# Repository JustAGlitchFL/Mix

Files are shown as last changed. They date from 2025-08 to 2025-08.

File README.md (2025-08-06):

# Mix
A multipurpose audio-focused console

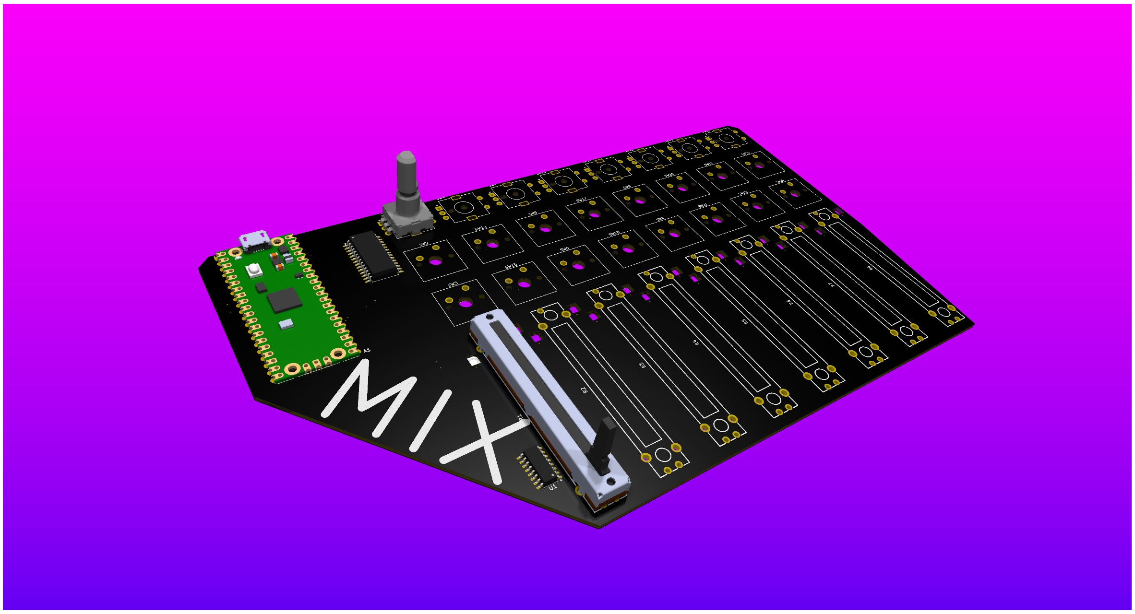
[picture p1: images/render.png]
render

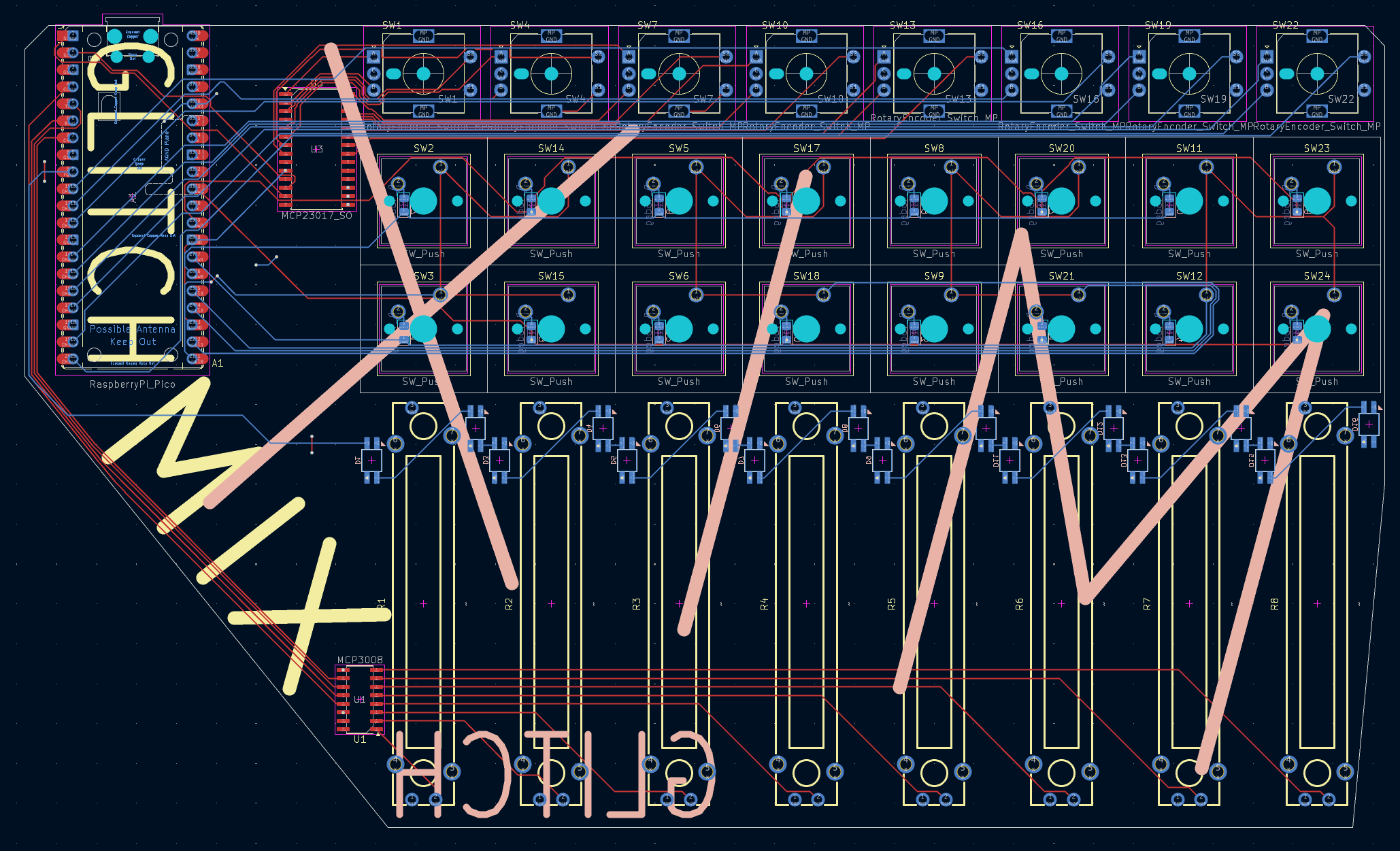
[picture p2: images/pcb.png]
pcb

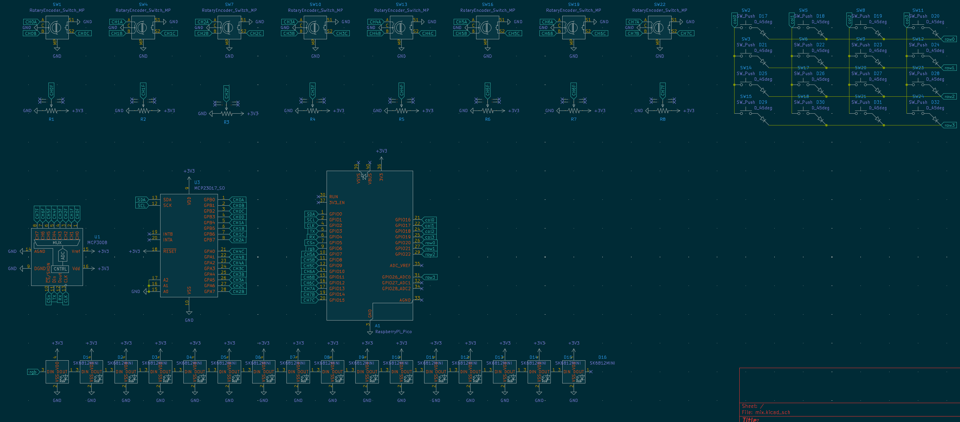
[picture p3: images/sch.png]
sch

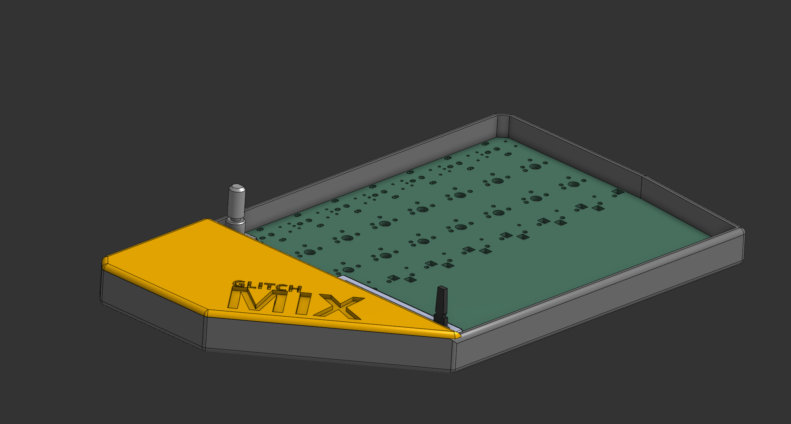
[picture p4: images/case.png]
case


## Why
I find myself constantly tuning my audio mix from different apps through windows, and would like a panel to adjust levels on the fly. I also wanted to use this for mixing audio for music and video projects, so I included 8 channels. Each channel has a slider for feed volume, an encoder for monitoring volume, a solo button, and a mute button. Everything is remappable to select functions for your usecase. I also included 2 neopixels per channel, one for status, and one for leveling by color.

## Assembly
Like [Timeline](https://github.com/justaglitchfl/timeline), ~~no case for this one~~ CASE FILES AVAILABLE NOW, as I want that raw PCB aesthetic. Solder everything together, good luck with the SMD for the ADC and IO expander! Might do a case when I get to uni and have access to actually functional printers if I get tired of the pcb as is. As with my other projects recently, drop some 3M 2229 on the back to protect it/the table, and to keep it in place (I love this stuff).

## BOM
|q  |part |link |price |total  |
|---|---|---|---|---|
|1  |pcb | |$42.60 |$128.78|
|16 |switches |https://www.amazon.com/Kailh-Box-Switches-Mechanical-Keyboards/dp/B09WYVJ4F9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|$25.98 | |
|8  |ECE11 |https://lcsc.com/product-detail/Rotary-Encoders_ALPSALPINE-EC11E18244AU_C202365.html |$15.71 | |
|8  |slide potentiometer |https://lcsc.com/product-detail/Potentiometers-Variable-Resistors_BOURNS-PTA4543-2015DPB103_C17444183.html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 |$14.16 | |
|1  |MCP23017_SO |https://lcsc.com/product-detail/I-O-Expanders_MICROCHIP-MCP23017T-E-SO_C629440.html?s_z=n_MCP23017_SO |$1.94 | |
|1  |MCP3008 |https://lcsc.com/product-detail/Analog-to-Digital-Converters-ADC_MICROCHIP-MCP3008T-I-SL_C2651321.html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 |$3.30 | |
|16 |0805 signal diode | |have on hand| |
|16 |sk6812 mini e | |have on hand| |
|1  |pi pico usbc (i wan orph pico)|https://www.aliexpress.us/item/3256807183354679.html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 |$3.56 | |
|1  |lcsc s+h | |$21.53 | |

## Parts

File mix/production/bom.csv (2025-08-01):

Designator | Footprint | Quantity | Value | LCSC Part #
A1 | RaspberryPi_Pico_Common_Unspecified | 1 | RaspberryPi_Pico
D1, D10, D11, D12, D13, D14, D15, D16, D2, D3, D4, D5, D6, D7, D8, D9 | SK6812MINI-E | 16 | SK6812MINI
D17, D18, D19, D20, D21, D22, D23, D24, D25, D26, D27, D28, D29, D30, D31, D32 | 0805 | 16 | D_45deg
R1, R2, R3, R4, R5, R6, R7, R8 | RES-ADJ_PTA4543-2015CPB102 | 8 | ~
SW1, SW10, SW13, SW16, SW19, SW22, SW4, SW7 | RotaryEncoder_Alps_EC11E-Switch_Vertical_H20mm_MountingHoles | 8 | RotaryEncoder_Switch_MP
SW11, SW12, SW14, SW15, SW17, SW18, SW2, SW20, SW21, SW23, SW24, SW3, SW5, SW6, SW8, SW9 | SW_Cherry_MX_1.00u_PCB | 16 | SW_Push
U1 | SOIC-16_3.9x9.9mm_P1.27mm | 1 | MCP3008
U3 | SOIC-28W_7.5x17.9mm_P1.27mm | 1 | MCP23017_SO

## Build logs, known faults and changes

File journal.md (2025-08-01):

Total Hours: 13
---
title: "Mix"
author: "rowyn"
description: "A multifunctional digital audio mixing console"
created_at: "2024-06-6"
---

## Getting it started: 7/8
Hours: 3
Thought up the general concept; started a schematic



## Getting it done: 7/9
Hours: 5
Planned implementation, researched IO expanders and ADCs, finished schematic, made pcb. I chose not to make a case here, as my printer is currently having issues, and I am kind of a fan of the raw pcb aesthetic regardless.


## Getting it done pt 2: 7/10
Finishing everything from the previous night
Hours: 4

## Realizing some issues: 7/31
Turns out some of the parts I initially selected were out of stock on LCSC, so I had to speedrun redoing part of the schematic, PCB, and adding the 3d models in the little bit of time I had throughout the day. I ended up getting it submitted at 11:59 PM EST, in the last few seconds before the deadline. I also added the 3d models of as many parts as I could (just one of each for limited time). I got the BOM finished, all the images saved, wrote a README, and submitted all in slightly less than an hour (locked tf in).
Hours: 1

render

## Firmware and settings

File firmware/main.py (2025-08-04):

import board
import analogio
import digitalio
import time
import pwmio
import busio
import adafruit_mcp3xxx.mcp3008 as MCP
from adafruit_mcp3xxx.analog_in import AnalogIn

# SPI MCP3008
spi = board.SPI()
cs = digitalio.DigitalInOut(board.D5)  # Chip select pin
mcp = MCP.MCP3008(spi, cs)
# analog input channels
chan0 = AnalogIn(mcp, MCP.P0)
chan1 = AnalogIn(mcp, MCP.P1)
chan2 = AnalogIn(mcp, MCP.P2)
chan3 = AnalogIn(mcp, MCP.P3)
chan4 = AnalogIn(mcp, MCP.P4)
chan5 = AnalogIn(mcp, MCP.P5)
chan6 = AnalogIn(mcp, MCP.P6)
chan7 = AnalogIn(mcp, MCP.P7)

# constants
min_value = 340
max_value = 65535
range = max_value - min_value
samples = 10  # number of samples to average for noise reduction

# deej interfacing

def noise_reduction(channel, samples=samples):
    smooth_value = sum(channel.value for _ in range(samples))
    return (max(0, smooth_value - min_value) * 1023) 

def read_channels():
    return {
        'chan0': noise_reduction(chan0),
        'chan1': noise_reduction(chan1),
        'chan2': noise_reduction(chan2),
        'chan3': noise_reduction(chan3),
        'chan4': noise_reduction(chan4),
        'chan5': noise_reduction(chan5),
        'chan6': noise_reduction(chan6),
        'chan7': noise_reduction(chan7)
    }

def send_deej_values(values):
    print('|'.join(map(str, values)))

# main loop
while True:
    values = read_channels()
    send_deej_values(values)
    time.sleep(0.1)

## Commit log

2025-08-06 Update BOM
2025-08-06 update bom csv
    [Mix BOM - Sheet1 (1).csv]
